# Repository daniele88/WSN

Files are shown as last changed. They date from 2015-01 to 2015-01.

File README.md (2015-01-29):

# WSN

This is my Master thesis in Computer Engineering developed with Gianfranco Costamagna.
We developed an energy aware wireless sensors network. The PCB of the network nodes is designed with Eagle, and it is made up of: a MSP430, a battery meter, a RTC (optional) and a CC2500 antenna.
The firmware of the microcontroller was developed with CCStudio, an IDE provided by TI.
The project could be built and tested with a MSP430 LaunchPad kit, provided by TI.
The library to manage communication between MSP and CC2500 via SPI are from alvarop (https://github.com/alvarop/msp430-cc2500)
See master_thesis.pdf (in Italian language) for further details on the PCB of the nodes, on the architecture of the network, and the communication protocol (written and designed from scratch)

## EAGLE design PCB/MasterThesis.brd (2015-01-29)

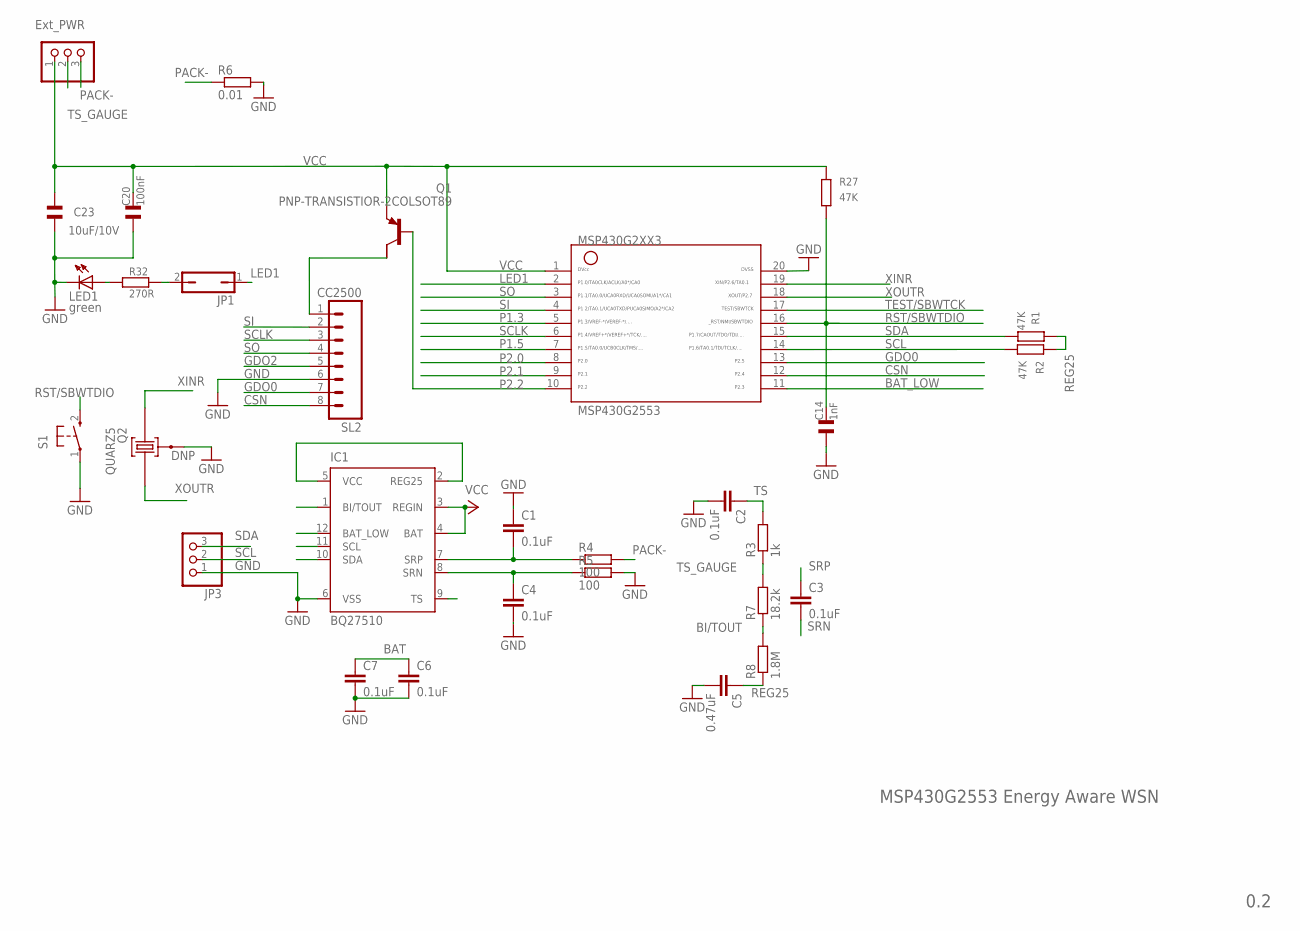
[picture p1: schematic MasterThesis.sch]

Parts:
C1, C2, C3, C4, C6, C7: 0.1uF; C025-024X044
C5: 0.47uF; C025-024X044
C14: 1nF; 0603
C20: 100nF; 0603
C23: 10uF/10V; 0805
IC1: BQ27510; DRZ; MPN BQ27510DRZT
J6: 1X03
JP1: JP1Q; JP1
JP3: PINHD-1X3/90; 1X03/90
LED1: green; DIODE0603
MSP430G2553: MSP430G2553; N20
Q1: PNP-TRANSISTIOR-2COLSOT89; SOT89
Q2: QUARZ5
R1, R2, R27: 47K; 0603
R3: 1k; 0204/5
R4, R5: 100; 0204/5
R6: 0.01; 0204/5
R7: 18.2k; 0204/5
R8: 1.8M; 0204/5
R32: 270R; 0603
S1: PB; PBTH
SL2: CC2500; 08P

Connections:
BAT: C6.1, C7.1, IC1.3 (REGIN), IC1.4 (BAT)
BAT_LOW: IC1.12 (BAT_LOW), MSP430G2553.11
BI/TOUT: IC1.1 (BI/TOUT), R7.1, R8.2
CSN: MSP430G2553.12, SL2.8
GDO0: MSP430G2553.13, SL2.7
GDO2: SL2.5
GND: C1.1, C2.2, C4.2, C5.2, C6.2, C7.2, C14.1, C20.1, C23.1, IC1.6 (VSS), JP3.1, LED1.K (C), MSP430G2553.20, Q2.GND@0 (0), R5.2, R6.2, S1.1, SL2.6
LED1: JP1.1, MSP430G2553.2
unnamed: Q1.2 (C), SL2.1
unnamed: JP1.2, R32.2
unnamed: LED1.A, R32.1
P1.3: MSP430G2553.5
P1.5: MSP430G2553.7
P2.0: MSP430G2553.8
P2.1: MSP430G2553.9
P2.2: MSP430G2553.10, Q1.1 (B)
PACK-: J6.3, R4.2, R6.1
PWPD: IC1.EXP@1 (PWPD), IC1.EXP@2 (PWPD), IC1.EXP@3 (PWPD), IC1.EXP@4 (PWPD), IC1.EXP@5 (PWPD), IC1.EXP@6 (PWPD), IC1.EXP@7 (PWPD), IC1.EXP@8 (PWPD), IC1.EXP@9 (PWPD)
REG25: C5.1, IC1.2 (REG25), IC1.5 (VCC), R1.1, R2.1, R8.1
RST/SBWTDIO: C14.2, MSP430G2553.16, R27.2, S1.2 (S)
SCL: IC1.11 (SCL), JP3.2, MSP430G2553.14, R2.2
SCLK: MSP430G2553.6, SL2.3
SDA: IC1.10 (SDA), JP3.3, MSP430G2553.15, R1.2
SI: MSP430G2553.4, SL2.2
SO: MSP430G2553.3, SL2.4
SRN: C3.2, C4.1, IC1.8 (SRN), R5.1
SRP: C1.2, C3.1, IC1.7 (SRP), R4.1
TEST/SBWTCK: MSP430G2553.17
TS: C2.1, IC1.9 (TS), R3.2
TS_GAUGE: J6.2, R3.1, R7.2
VCC: C20.2, C23.2, J6.1, MSP430G2553.1, Q1.3 (E), R27.1
XINR: MSP430G2553.19, Q2.2
XOUTR: MSP430G2553.18, Q2.1

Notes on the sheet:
MSP430G2553 Energy Aware WSN
Ext_PWR
DNP
0.2

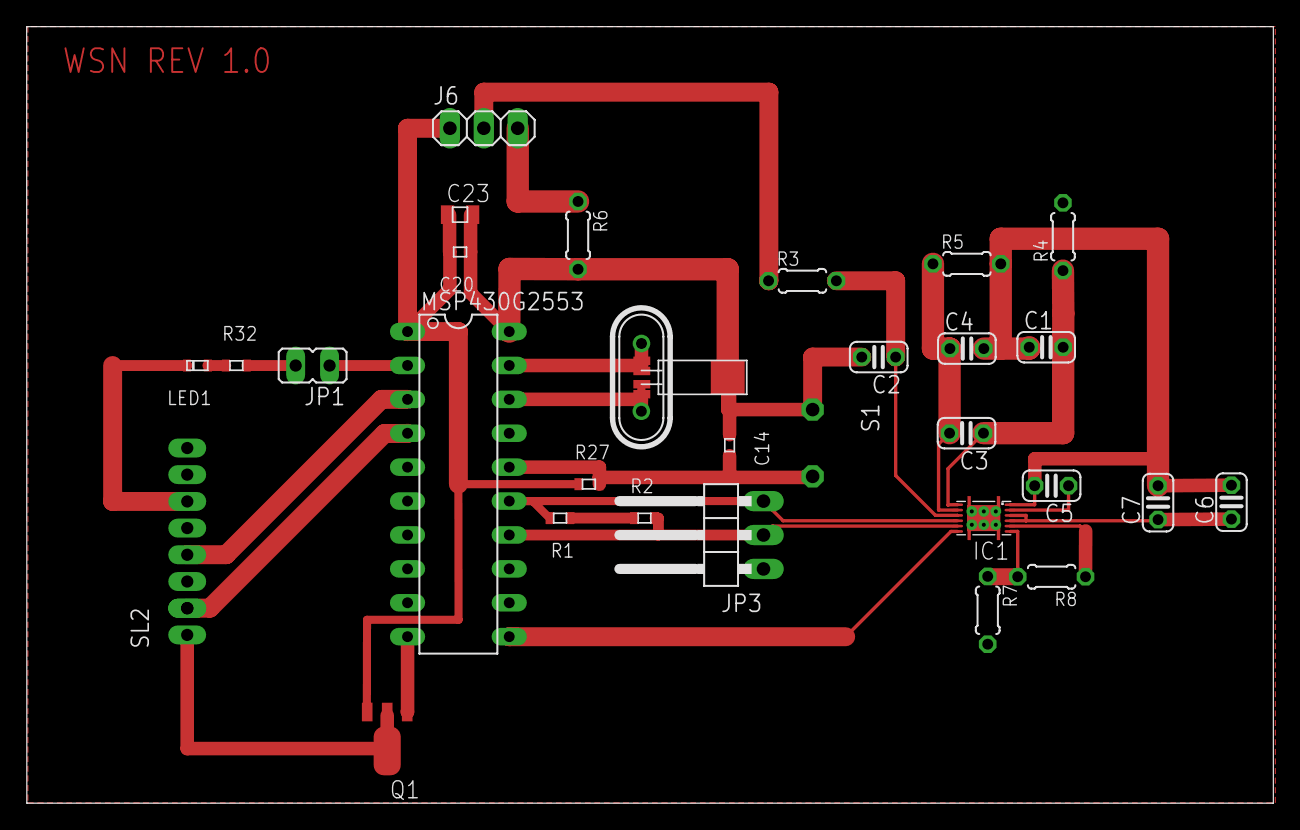
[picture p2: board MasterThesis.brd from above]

Board: 2 copper layers, 93.4 x 58.2 mm, 30 parts (0 on the bottom side), 27 nets.

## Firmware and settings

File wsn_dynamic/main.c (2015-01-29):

#include "msp430g2553.h"
#include <stdint.h>
#include <stdlib.h>
#include "lib/define.h"
#include "lib/utils.h"
#include "lib/queue.h"
#include "lib/g2553.h"
#include "lib/cc2500.h"
#include "lib/spi.h"

//#define MAC_SINK 0 //comment or uncomment to be the sink
#define DEBUG_0 //comment or uncomment to read from the battery meter or generate random numbers
#define DEBUG_1 //comment or uncomment to blink the led when a packet is received

/*
 * Global variables
 */

uint8_t my_beacon[BEACON_HEADER+N_SENSORS];
packet_t* txBuffer_data;
int16_t rssi;
uint8_t power=0xFF;
int beacon_loss=0, packet_send=0, next_hop=1, soc_next_hop=0, n_hop=255,k=0,n_wakeup=-1,wait_for_mac=0, my_mac, mac_not_set=1;
int window[N_SENSORS];
volatile int n_beacon_received=0,data_received,panic=1;
volatile int ok=0;

#ifdef MAC_SINK
int mac_array[N_SENSORS];
#endif
volatile short soc=100;

uint8_t cc2500_rx_callback(uint8_t*, uint8_t );
void Read_data();
void Read_i2c_dummy();
void Panic();

/********************************************************************************************************************************
 ************************************************** Main program ****************************************************************
 ********************************************************************************************************************************/

void main(void)
{
	volatile int i;
	int min, max;
#ifdef MAC_SINK
	volatile long int j=0;
#endif

	WDTCTL = WDTPW + WDTHOLD; // Stop WDT
	BCSCTL3 |= XCAP_3; //12.5pF cap- setting for 32768Hz crystal

	// Setup oscillator for 16MHz operation for cc2500
	BCSCTL1 = 0xD9; //D9 -> 11011001;

	// Wait for changes to take effect
	__delay_cycles(4000);
	LED_PxOUT &= ~(LED1); //Outputs
	LED_PxDIR = LED1; //Outputs
	BCSCTL2 = DIVS_2; // SMCLK source its freq from MCLK/8
	P2DIR |= BIT2;
	P1SEL |= BIT6 + BIT7; // Assign I2C pins to USCI_B0
	P1SEL2|= BIT6 + BIT7; // Assign I2C pins to USCI_B0

	CCTL0 = CCIE; // CCR0 interrupt enabled
	CCR0 = 8192; // 512 -> 1 sec, 30720 -> 1 min
	TACTL = TASSEL_1 + ID_3 + MC_1; // ACLK, /8, upmode

	setup_cc2500(cc2500_rx_callback); //setup in rx mode

	cc2500_disable_addressing();

	UCB0CTL0 = UCMST + UCMODE_3 + UCSYNC; // I2C Master, synchronous mode
	UCB0CTL1 = UCSSEL_2 + UCSWRST; // Use SMCLK, keep SW reset
	UCB0BR0 = 12; // fSCL = SMCLK/12 = ~100kHz
	UCB0BR1 = 0;
	UCB0I2CSA = 0x055; // Slave Address is 055h
	UCB0CTL1 &= ~UCSWRST; // Clear SW reset, resume operation
	IE2 |= UCB0RXIE + UCB0TXIE; // Enable RX, TX interrupt

	// Build packet
	/*txBuffer[0] = 6;         // Packet length n.b. for dummies -> last index!!!
	txBuffer[1] = 0x01;      // Packet source address
	txBuffer[2] = 0xFF;		// Packet destination address
	txBuffer[3] = 0xFF;		// Packet next hop address
	txBuffer[4] = 0x00;		// Packet type
	txBuffer[5] = 0x02;		// data
	txBuffer[6] = 0x06;*/

#ifdef MAC_SINK
	my_beacon[1] = MAC_SINK;
	my_beacon[4] = 0;
	for (i=0;i<N_SENSORS;i++)
		mac_array[i]=0;
#else
	my_beacon[4] = N_SENSORS+1; // number of sensors
#ifdef DEBUG_0
	srand(TAR);
	soc=rand()%30+70;
#else
	Read_i2c();
#endif
#endif
	my_beacon[3] = 	soc;
	my_beacon[2] = 0;
	my_beacon[0] = 4;

	while(1)
	{
		// I am the sink
#ifdef MAC_SINK
		__bis_SR_register(LPM3_bits + GIE); // Enter LPM3 w/interrupt
		cc2500_turn_on();
		cc2500_tx(my_beacon, my_beacon[0]+1); //change setup to tx mode
		cc2500_set_rx();
		//blink(my_beacon[3]);
#ifdef DEBUG_1
		blink(1, 30000);
#endif
		while(TAR<(WINDOW_TIME+OFFSET));
		cc2500_turn_off();
#else
		// i am a normal sensor
		if (panic) // i don't know any other sensors
			Panic();

		__bis_SR_register( LPM3_bits + GIE );   // Enable interrupts and sleep

#ifdef DEBUG_0
		Read_i2c_dummy();
#else
		Read_i2c();
#endif

		// if i am the sensor with lower battery, update beacon
		my_beacon[3] = (soc < soc_next_hop) ? soc : soc_next_hop;

		if((++n_wakeup%N_DISCOVERY)==0)
			inizialize_window(window);

		//while (TAR<OFFSET);

		get_min_max(window, &min,&max);
		if(min>1) // min!=0 && min!=1
			while(TAR<(WINDOW_TIME/N_SENSORS*(min-1)));
		cc2500_turn_on();
		/*if(min==0 || min==1)
			while (TAR<OFFSET);
		else
			while (TAR<ONE_SECOND/N_SENSORS*(min-1));*/

		for (k=min;k<=max;k++)
		{
			data_received=0;
			if (mac_not_set)
			{
				if (!wait_for_mac){
					if (min>1)
						while(TAR<(WINDOW_TIME/N_SENSORS*(min-1))+OFFSET); // + rand()%WINDOW_TIME/N_SENSORS+
					else
						while(TAR<OFFSET);
					uint8_t* dhcp_request=make_dhcp_request(next_hop);
					cc2500_tx(dhcp_request, dhcp_request[0]+1);
					cc2500_set_rx();
				}
				while(TAR<(WINDOW_TIME+OFFSET)); //wait for all the window!!
				wait_for_mac = (++wait_for_mac==3) ? 0 : wait_for_mac;
				break;
			}
			else {
				if (k==my_mac) // it's my turn to send data
				{
					//do
					//{
					cc2500_set_power(0xFF); 	// set maximum power to transmit my beacon

					cc2500_tx(my_beacon, my_beacon[0]+1); //change setup to tx mode and send my beacon
					inc_window(window, k);
					// send all data i have in my queue
					cc2500_set_power(power);  //set power as desired by other nodes
					packet_t* pointer =  txBuffer_data -> next; //First node is dummy node.
					// Iterate through the entire list
					while(pointer!=NULL)
					{
						cc2500_tx(pointer->data, pointer->data[0]+1); //change setup to tx mode and send data
						pointer = pointer -> next; //Go to the next node.
					}
					//}
					//while(TAR<(ONE_SECOND/N_SENSORS*k+OFFSET));
					cc2500_set_rx();
				}
				while(TAR<(WINDOW_TIME/N_SENSORS*k+OFFSET)); // 2048 -> one second
				if (data_received)
					inc_window(window, k);
				else if (k!=my_mac)
					dec_window(window, k);
			}
		}
		cc2500_turn_off();

		if(n_beacon_received)
		{
			n_beacon_received = 0;
			beacon_loss=0;
#ifdef DEBUG_1
			blink(1, 30000);
#endif
		}
		else
			panic = (++beacon_loss==N_BEACON_PANIC) ? 1 : 0;

		// while(TAR<(2048+10)); // wait for all the other time windows
#endif
	}
}

/********************************************************************************************************************************
 ************************************************** End main program ************************************************************
 ********************************************************************************************************************************/

// This function is called to process the received packet
uint8_t cc2500_rx_callback( uint8_t* buffer, uint8_t length )
{
	int i;
	/* Build data packet
	txBuffer[0] = 5;         // Packet length n.b. for dummies -> last index!!!
	txBuffer[1] = 0x01;      // Packet source address
	txBuffer[2] = 0xFF;		// Packet type
	txBuffer[3] = 0xFF;		// Packet next hop address
	txBuffer[4] = 0x00;		// Packet destination address
	txBuffer[5] = 0x02;		// data
	 */

	/* Build beacon packet
	txBuffer[0] = 4;         // Packet length n.b. for dummies -> last index!!!
	txBuffer[1] = 0x01;      // Packet source address
	txBuffer[2] = 0x00;		// Packet type
	txBuffer[3] = 0x10;		// soc
	txBuffer[4] = 0x10;		// num hop
	 */

#ifdef MAC_SINK
	if (buffer[1]==0x03)  // packet type dhcp_discover
	{
		//send back dhcp_response
		uint8_t dhcp_response[PACKET_SIZE];
		dhcp_response[0]=PACKET_SIZE+1;
		dhcp_response[2]=0x04; // type dhcp response
		dhcp_response[1]=buffer[0]; // ID
		int z=N_SENSORS;
		int has_mac=0;
		// has the node already have a MAC or not?
		do{
			if (mac_array[--z]==buffer[0]) {
				has_mac=1;
				break;
			}
		}
		while(z>0);

		if (has_mac)
			dhcp_response[3]=z;
		else
		{
			//find a free MAC (zero is reserved for sink)
			z=N_SENSORS;
			do{
				if (!mac_array[--z]) {
					mac_array[z]=buffer[0];
					dhcp_response[3]=z;
					break;
				}
			}
			while(z>0);
		}

		if (TAR<WINDOW_TIME/N_SENSORS)
			cc2500_tx(dhcp_response, dhcp_response[0]+1);
		else
			insert(txBuffer_data, dhcp_response, dhcp_response[0]+1); //TODO check array index!!
		cc2500_set_rx();
	}
	//__no_operation();
#endif

#ifndef MAC_SINK
	if (buffer[1]==0x00) // i received a beacon
	{
		if (buffer[0] == next_hop) // beacon is from my next hop
		{
			reset_tar(WINDOW_TIME/N_SENSORS*buffer[0]+OFFSET);  // let's synchronize
			soc_next_hop = buffer[2];
			//power=buffer[4]; // my next hop tells me how to setup my transmit power
			panic = 0;
			//panic = (soc_next_hop < MIN_SOC) ? 1 : 0;
			for(i=0;i<N_SENSORS;i++) // to scan all the ack received in my next hop's beacon
				my_delete(txBuffer_data, i, buffer[BEACON_HEADER+i]); //delete all packet from my tx queue that my next hop has already received
		}
		// the packet was from someone else
		else if (buffer[3] <= my_beacon[4] || panic)
			if ((buffer[3] == my_beacon[4] && buffer[2] > soc_next_hop) || panic)
			{
				//i have found a better next hop or i am in panic so i accept everything
				reset_tar(WINDOW_TIME/N_SENSORS*buffer[0]+OFFSET); // let's synchronize
				next_hop = buffer[0];
				soc_next_hop = buffer[2];
				panic = 0;
				my_beacon[4] = ++(buffer[3]);
			}
		n_beacon_received=1;
	}
	else if (buffer[1]==0x01)// i received data
	{
		rssi= rssi_to_dbm(buffer[length]);
		if (buffer[0] == my_mac) //check if it's for me
		{
			// the packet is for me so save data, process it or do whatever you want here
			// ....
		}
		else if (buffer[2] == my_mac) //check if i am the next hop for the sender -> n.b. data is travelling to the sink!!
		{
			//i have to check if i have enough free space in my queue to put the new packet
			//if not the packet is discarded (the sender will not receive the ack so it will try again later to send me the data)
			//it's done also to be sure i don't go into another window sending too many packets when it's my turn to send data
			if (packet_send<CC2500_BUFFER_LENGTH)
			{
				insert(txBuffer_data, buffer, next_hop);
				++packet_send;
			}
		}
	}
	else if(buffer[1]==0x04 && buffer[0]==ID)
	{
		//i received my dhcp response
		my_mac=buffer[2];
		if (mac_not_set)
		{
			mac_not_set=0;
			wait_for_mac=0;
			my_beacon[1] = my_mac;
		}
	}
	else if(buffer[1]==0x03 && buffer[2]==my_mac)
		//i received a dhcp request, if i am the sender's next hop i have to propagate it to the sink
		insert(txBuffer_data, buffer, next_hop);
	data_received=1;
#endif

	return 0;
}

// Timer A0 interrupt service routine
#pragma vector=TIMER0_A0_VECTOR
__interrupt void Timer_A (void)
{
	//P1OUT ^= LED1;                      // Toggle P1.0 using exclusive-OR
	LPM3_EXIT;
}

#pragma vector=NMI_VECTOR
__interrupt void nmi_ (void)
{
	IFG1 &= ~OFIFG; // Clear OSCFault flag
	while (IFG1 & OFIFG); // OSCFault flag still set?
	IE1 |= OFIE; // Enable Osc Fault*/
}

// USCI_B0 Data ISR
#pragma vector = USCIAB0TX_VECTOR
__interrupt void USCIAB0TX_ISR(void)
{
	if(IFG2 & UCB0TXIFG)
	{
		IFG2 &= ~UCB0TXIFG;                     // Clear USCI_B0 TX int flag
		UCB0TXBUF = 0x2C; 						// Move RX data to TX
	}
	else if(IFG2 & UCB0RXIFG)
	{
		IFG2 &= ~UCB0RXIFG;                     // Clear USCI_B0 TX int flag
		soc = UCB0RXBUF;
	}
}

// USCI_B0 State ISR
#pragma vector = USCIAB0RX_VECTOR
__interrupt void USCIAB0RX_ISR(void)
{
	if (UCB0STAT & UCNACKIFG)
	{
		UCB0CTL1 |= UCTXSTP;
		UCB0STAT &= ~UCNACKIFG;
	}
	else if (UCB0STAT & UCSTTIFG)
		UCB0STAT &= ~UCSTTIFG;
}


void Read_data()
{
	//put data read from sensor into the queue to send it
	/*
	insert(...);
	++packet_send; //increment number of packet in the queue
	 */
}

void Read_i2c_dummy()
{
	soc-=(rand()%5);
	soc= (soc<0) ? 0 : soc;
}

void Panic()
{
	int i,j,n_panic=N_PANIC_LISTEN;
	__bis_SR_register(GIE);
	while (1)
	{
		P1OUT |= 0x01;
		cc2500_turn_on();
		for (i=0;panic && i<N_PANIC_LISTEN;i++) // i try N times to receive a beacon
		{
			while(TAR!=32768 && panic);
			for (j=0;j<100;j++);  // a little delay to let TAR increment from 32768
		}
		P1OUT &= 0xFE;
		cc2500_turn_off();
		if (!panic)
			break;
		__no_operation();
		// to save battery i sleep for a while (as the time goes far and i don't receive nothing i increment n_panic to sleep more and more
		for (i=0;i<n_panic;i++)
		{
			while(TAR!=32768);
			for (j=0;j<100;j++);  // a little delay to let TAR increment from 32768
		}
		++n_panic;
	}
}
